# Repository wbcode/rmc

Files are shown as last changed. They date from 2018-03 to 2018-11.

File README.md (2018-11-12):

### Why
> Because I could

### License
> Beerware 

### The beginning
> rmc (Remote Monitor Command) - project for my two monitors connected to raspberry pi:s. That I use for watching twitch and youtube. I have built a controller based on Arduino to control the raspberry pi:s. The controller launches programs and controls the volume. All communication is done over MQTT. I'm using this to I don't have to use VNC, ssh or connect a keybord and mouse.

> * Yes, I'm not a programmer so the once that know what they are doing will cry.

> * Yes, You can use this to execute commands that you shouldn't .ie wipe your system etc if you configure that...

> * Some day I may add "Alexa" or "Google home" to support voice command either as appliance or on a raspberry

### Pictures

### Hardware setup
* 2 raspberry pi 3
* 2 monitors
* 1 linux server
* 1 diy controller box

### Software
|directory|description|
|---|---|
|arduino|Code running on the Arduino controller box|
|client|Runs on the raspberry pi:s and listen for commands to execute|
|lib|Start/stop scripts for systemctl|
|pic|Pictures 
|server|Runs on the linux server (Ubuntu) and sends out unixtime to the Arduino*|
|web|HTML client to send commands, current running on the linux server|

### Raspberries:
> They are running a basic installation of raspbian so for every raspberry

> Clone the repository
```
git clone https://github.com/wbcode/rmc.git
```
> Install dependencies
```
pip install paho-mqtt
sudo apt install xdotool
```

> Add service for client
```
cd rmc
chmod 755 rmc.py
sudo cp lib/systemd/system/rmc.service /lib/systemd/system
sudo systemctl enable rmc.service
```
> Edit the configuration file to fit your commands and your local network
```
vi client/rmc.conf
```
> Start the rmc
```
sudo systemctl start rmc
```

#### Raspberries tweek options - use as needed
##### xdotool
> xdotool - used to move mouse, kill programs in X etc
```
sudo apt install xdotool
```

##### unclutter
> unclutter - hide the mouse point 
```
sudo apt install unclutter
echo "unclutter &" >> .xinitrc
```
##### chromium tweeks
>>Remove the chromium crashed dialog 
```
cd
vi .bashrc
```
> Add at the end
```
sed -i 's/"exited_cleanly":false/"exited_cleanly":true/' ~/.config/chromium/'Local State'
sed -i 's/"exited_cleanly":false/"exited_cleanly":true/; s/"exit_type":"[^"]\+"/"exit_type":"Normal"/' ~/.config/chromium/Default/Preferences
```

### Linux server
> Using mosquitto
> Add websocket listerner to mosquitto to be able to use HTML client:
```
vi /etc/mosquitto/conf.d/websocket.conf
```
> Make sure the following is in the file
```
listener 1883
listener 1884
protocol websockets
```
> Restart
```
sudo systemctl restart mosquitto
```

#### Options
> Since my linux server is always on and I have oled display on my controller I want to be able to display the current time. Without an RTC module the Arduino wanders away from real time pretty fast. So to sync time on Arduino it ask the linux server for the time.
> I'm using MQTT to do this since the Arduino NTP library will use to much memory and I already have the MQTT library in place.
> The only thing currently the server part of rmc is doing is to listen for time request in MQTT-topic **/pi/s/time** and response to that by publishing the current UNIX-time in MQTT-topic **/pi/c/time**
> So if you not using the feature or what to tweek it to fit your setup it's easy. You can run this part on one of the raspberries as well.

> Add service for client
```
cd rmc
chmod 755 rmc.py
sudo cp lib/systemd/system/rmcserver.service /lib/systemd/system
sudo systemctl enable rmcserver.service
```
> Edit the configuration file to fit your commands and your local network
```
vi server/rmcserver.conf
```
> Start the rmc
```
sudo systemctl start rmcserver
```

### Controller Arduino
> Hardware
```
1 - Arduino Nano
1 - 74HC165N (parallell to serial)
1 - 128x64 oled display (8 pin)
1 - W5100 Ethernet Shield Module
2 - 10k Slite pot  
8 - 220 resistors
10 - push on/off switches
```

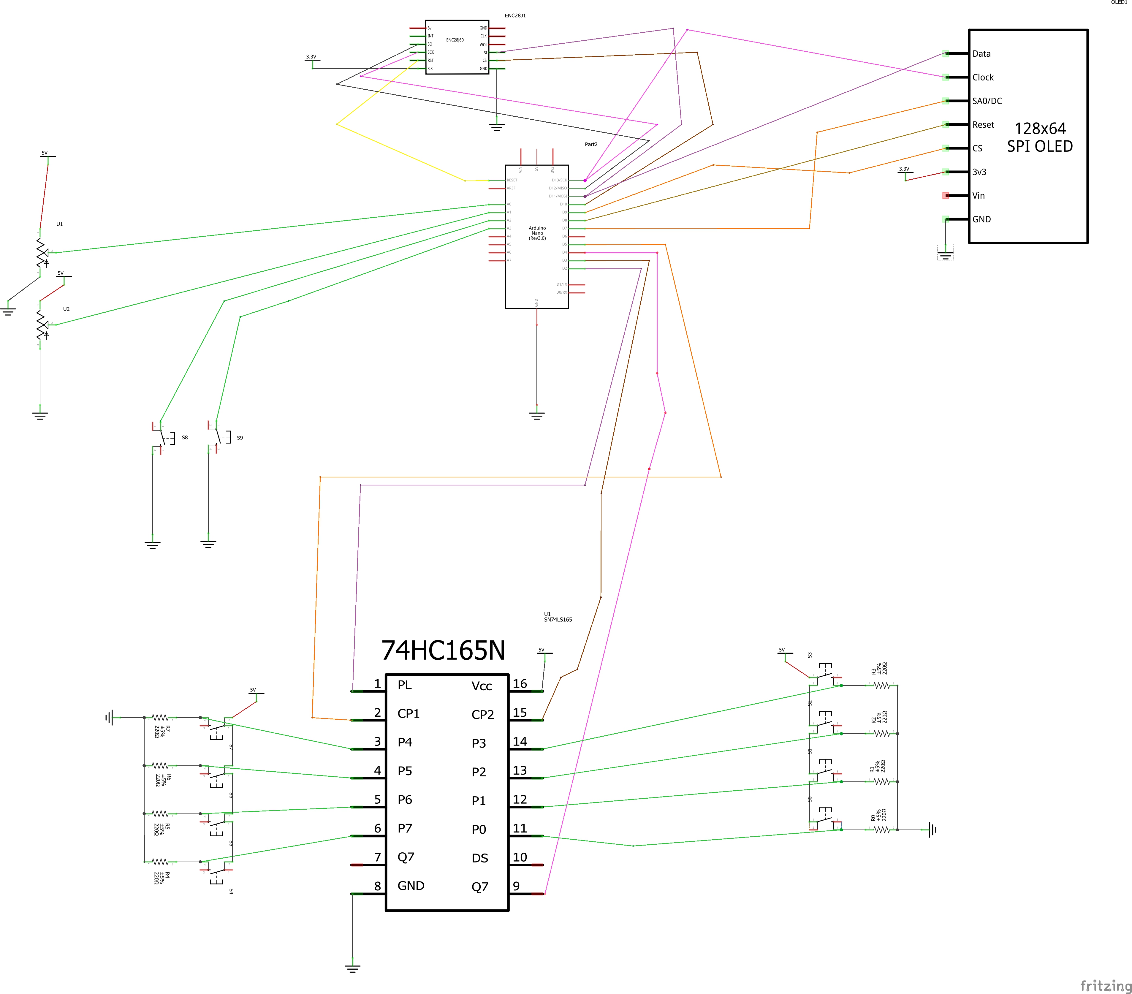
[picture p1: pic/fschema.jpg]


### MQTT communication flows
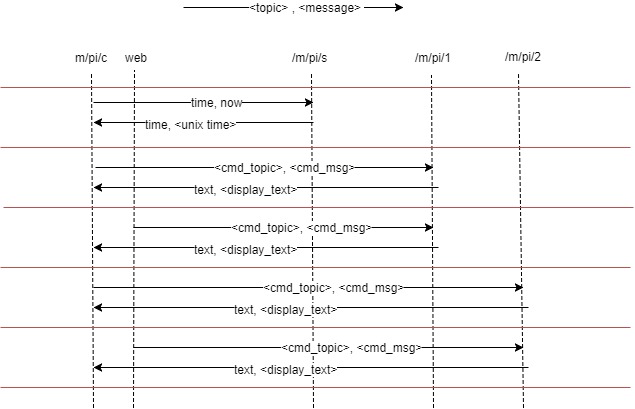
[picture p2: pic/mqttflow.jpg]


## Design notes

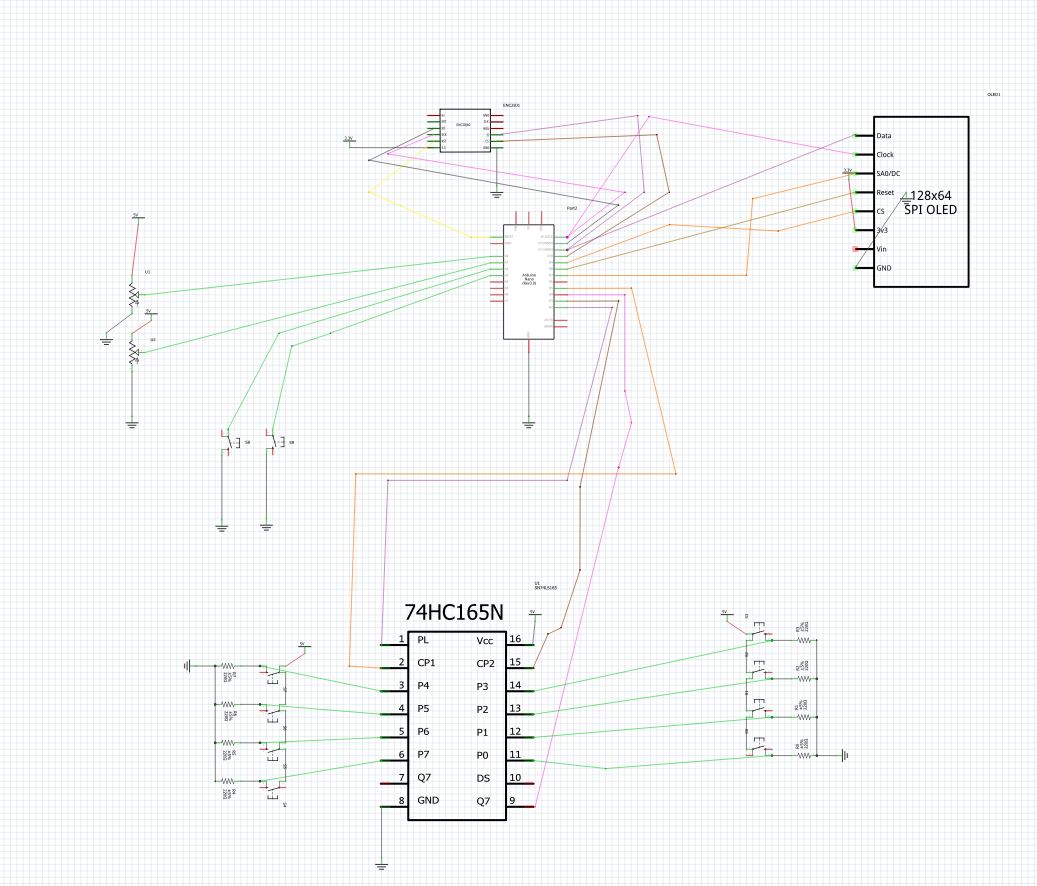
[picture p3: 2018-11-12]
pic/fschema.JPG

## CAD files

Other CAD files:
pic/controller.skp
pic/controller_sides.skp

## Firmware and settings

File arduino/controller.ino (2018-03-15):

/*

TAKE A MIN TO READ THIS!

rmc controller using mqtt to controll two raspberry pi:s that I use as display screens for twitch/youtube/photo:s etc.

NOTE: I manged to use some pins that will not allow you to upload the code to the arudino while it's connected to all the accessories. 

NOTE: Replace the mac address, client ip and server ip for the mqtt.

License: Beerware, Wineware or Whiskeyware

https://github.com/wbcode/rmc

*/

#include <SPI.h>
//#include <UIPEthernet.h> /*You can use a ENC28J60 module but it will be unstable, frezzening the arudino anything from startup to 2 days*/
#include <Ethernet.h>
#include <PubSubClient.h>
#include <SSD1306Ascii.h>
#include <SSD1306AsciiSpi.h>


/*
 * SCLK : SCK, CLK.
 * MOSI : SIMO, SDO, DO, DOUT, SO, MTSR.
 * MISO : SOMI, SDI, DI, DIN, SI, MRST.
 * SS : nCS, CS, CSB, CSN, nSS, STE, SYNC.
 */


/* Connecting things up
 *  OLED  ETH  165   ARD    POT1    POT2  BTN1  BTN2
 *  VCC   X     X    3.3V     X       X     X     X
 *  GRD   GRD  GRD   GRD     GRD     GRD   GRD   GRD  
 *  CS    X     X    9        X       X     X     X
 *  X     SS    X    10       X       X     X     X
 *  X     RST   X    RST      X       X     X     X
 *  RST   X     X    8        X       X     X     X
 *  DO    CK    X    13       X       X     X     X
 *  D1    MO    X    11       X       X     X     X
 *  X     MI    X    12       X       X     X     X
 *  DC    X     X    7        X       X     X     X
 *  X     X     1    2        X       X     X     X
 *  X     X     2    5        X       X     X     X
 *  X     X     9    4        X       X     X     X
 *  X     X    15    3        X       X     X     X
 *  X    VCC   VCC   5V      VCC     VCC   VCC   VCC
 *  X     X     X    A0      OTA      X     X     X
 *  X     X     X    A1       X      OTA    X     X
 *  X     X     X    A2       X       X    OTA    X
 *  X     X     X    A3       X       X     X    OTA
 */


// pin definitions
#define OLED_DC   7 
#define OLED_CS   9 /* SS */
#define OLED_CLK  13 /*SCLK*/
#define OLED_DATA 11 /*MOSI*/
#define OLED_RST   8
#define ETH_CS 10 /*SS*/

#define HC165_L 2 /* pin 1*/
#define HC165_CLK_E 3 /* pin 15*/
#define HC165_DIN 4 /* pin 9*/
#define HC165_CLK 5 /* pin 2*/




// Update these with values suitable for your hardware/network.
byte mac[]    = {  0xDE, 0xEA, 0xBA, 0xFE, 0xFE, 0xED };
/*server and client ip moved from here to save global memory*/

SSD1306AsciiSpi oled;

unsigned long unixtime = 0;
unsigned long gotunixtime = 0;
unsigned long last_clock = 0;
unsigned long lasttimerequest = 0;
unsigned long time_texted = 0;
boolean updatetime = false;
boolean texted = false;
byte lastdigA2= HIGH;
byte lastdigA3= HIGH;
int volumeR, volumeL=0;
byte lastbyte =0;

void callback(char* topic, byte* payload, unsigned int length) {
  char p[length];
  memcpy(p,(char *) payload, length);
  if (!strcmp(topic,"/pi/m/c/time")) {
     gotunixtime = millis();
     last_clock = gotunixtime;
     unixtime = strtoul(p,NULL,10);
     updatetime=true;
     oled_display_time();
  } else if (!strcmp(topic,"/pi/m/c/text")) {
      texted = true;
      time_texted =  millis();
      oled.clear(0,127,0,0);
      oled.setCursor((123 - (length*5))/2,0);
      oled.println(p);
  }    
  //free(p);
}

EthernetClient ethClient;
PubSubClient client;

long lastReconnectAttempt = 0;

boolean reconnect() {
  if (client.connect("controller")) {;
    client.subscribe("/pi/m/c/#");
    delay(2500); //needed to be able to get the time
    client.publish("/pi/m/s/time","now");
    // ... and resubscribe
  }
  return client.connected();
}

void oled_display_time() {
     unsigned long t,m,h,s =0;
     char st[9] = {'\0'};
     t=unixtime + ((last_clock-gotunixtime)/1000);
     s = t % 60;
     t /=60;
     m = t % 60;
     t /=60;
     h = t % 24;
     sprintf(st,"%02lu:%02lu:%02lu",h,m,s);
     //oled.set1X();
     oled.setCursor(28,3);
     oled.println("- WORLDRULER -");
     oled.setCursor(46,4);
     oled.println(st);
     sprintf(st,"L: %3d %%\0",volumeL);
     oled.setCursor(0,7);
     oled.print(st);
     oled.setCursor(80,7); 
     sprintf(st,"R: %3d %%\0",volumeR);
     oled.print(st);
}

void readInput() {
  digitalWrite(HC165_L,LOW);
  delayMicroseconds(5);
  digitalWrite(HC165_L,HIGH);
  delayMicroseconds(5);
   
  digitalWrite(HC165_CLK,HIGH);
  digitalWrite(HC165_CLK_E,LOW);
  byte in = shiftIn(HC165_DIN, HC165_CLK,MSBFIRST);
  digitalWrite(HC165_CLK_E,HIGH);

  if (in!=lastbyte) {
    lastbyte=in;
    switch(in) {
      
      case B00000001:
         client.publish("/pi/m/1/macro","1");
      break;
      case B00000010: 
         client.publish("/pi/m/1/macro","2");
      break;
      case B00000100: 
         client.publish("/pi/m/1/macro","3");
      break;
      case B00001000: 
         client.publish("/pi/m/1/macro","4");
      break;
      case B00010000: 
         client.publish("/pi/m/2/macro","1");
      break;
      case B00100000: 
         client.publish("/pi/m/2/macro","2");
      break;
      case B01000000: 
         client.publish("/pi/m/2/macro","3");
      break;
      case B10000000: 
         client.publish("/pi/m/2/macro","4");
      break;
     }
    }
    byte digA2 = digitalRead(A2);
    byte digA3 = digitalRead(A3);
     
    if((digitalRead(A2) == LOW) && digA2 != lastdigA2) {
      client.publish("/pi/m/1/macro","5");
    }

    if((digitalRead(A3) == LOW) && digA3 != lastdigA3) {
      client.publish("/pi/m/2/macro","5");
    }
    lastdigA2 = digA2;
    lastdigA3 = digA3;
    
}

void readVolume() {
  int value = analogRead(A1);          
  value = map(value, 0, 1023, 0, 100);
  if (!(volumeR == value || volumeR+1 == value  || volumeR-1 == value )) {
    volumeR = value;
    char vcmd[8]= {"\0"};
    sprintf(vcmd,"set %d",volumeR);
    client.publish("/pi/m/2/volume",vcmd);
  }
  value = analogRead(A0);          
  value = map(value, 0, 1023, 0, 100);
  if (!(volumeL == value || volumeL+1 == value  || volumeL-1 == value )) {
    volumeL = value;
    char vcmd[8]= {"\0"};
    sprintf(vcmd,"set %d",volumeL);
    client.publish("/pi/m/1/volume",vcmd);
  }
}

void setup()
{

  pinMode(ETH_CS, OUTPUT); /*Make sure that SS on arduino is set to output*/
  pinMode(OLED_CS, OUTPUT);
  pinMode(HC165_L, OUTPUT);
  pinMode(HC165_CLK_E, OUTPUT);
  pinMode(HC165_DIN, INPUT);
  pinMode(HC165_CLK, OUTPUT);
  pinMode(A2, INPUT_PULLUP);
  pinMode(A3, INPUT_PULLUP);
  
 

  /* IP for server and client*/
  IPAddress ip(10, 10, 11, 43);
  IPAddress server(10, 10, 11, 101);

  oled.begin(&Adafruit128x64, OLED_CS, OLED_DC,OLED_RST);
  oled.setFont(Adafruit5x7);
  oled.clear();
  oled.println("Booting...");
 
  Ethernet.begin(mac, ip);
  
  oled.println(Ethernet.localIP());

  char cmac[18];
  sprintf(cmac, "%2X:%2X:%2X:%2X:%2X:%2X", mac[0], mac[1], mac[2], mac[3], mac[4], mac[5]);
  
  oled.println(cmac);
  oled.setCursor(20,6);
  oled.print(".. by wbcode ..");
  delay(2500);

  client.setClient(ethClient);
  client.setServer(server, 1883);
  client.setCallback(callback);
  
  lastReconnectAttempt = 0;

  oled.clear();
  oled.setCursor(28,3);
  oled.println("- WORLDRULER -");
  //Serial.begin(115200);
}

void loop()
{
   
   long now = millis();
   
   if (!client.connected()) {
    if (now - lastReconnectAttempt > 5000) {
      lastReconnectAttempt = now;
      // Attempt to reconnect
      if (reconnect()) {
        lastReconnectAttempt = 0;
      }
    }
  } else {
    // Client connected
    client.loop();

      /*Clock update on oled*/
    if (( now - last_clock) > 1000 && gotunixtime !=0) {
      last_clock=millis();
      oled_display_time();
      if (texted && (millis()- time_texted > 5000)) {
        oled.clear(0,127,0,0);
      }
    }
    /*sync clock every min*/
    if(( now - gotunixtime) > 60000  && (now - lasttimerequest) > 5000 ) {
      client.publish("/pi/m/s/time","now");
      updatetime = false;
      lasttimerequest = now;
    }
    /*Check input but every 100ms*/
    if (( now - last_clock) > 100) {
      readVolume();
      readInput();
    }  
  } 
 
}

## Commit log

2018-01-13 new structure for server, client and arduino
2018-03-15 Adding arduino code
2018-03-16 Adding schema and flow diagram
    [control.fzz]
2018-03-17 Sketup files for controller box
    [controller.skp, controller_sides.skp]
